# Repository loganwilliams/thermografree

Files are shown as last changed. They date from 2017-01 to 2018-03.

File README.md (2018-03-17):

# Thermografree

Thermografree is the first open source, medium resolution, and broadband forward looking infrared (FLIR) camera. It can be used as a thermographic camera, or for scientific imaging applications in the 2-18 um range.

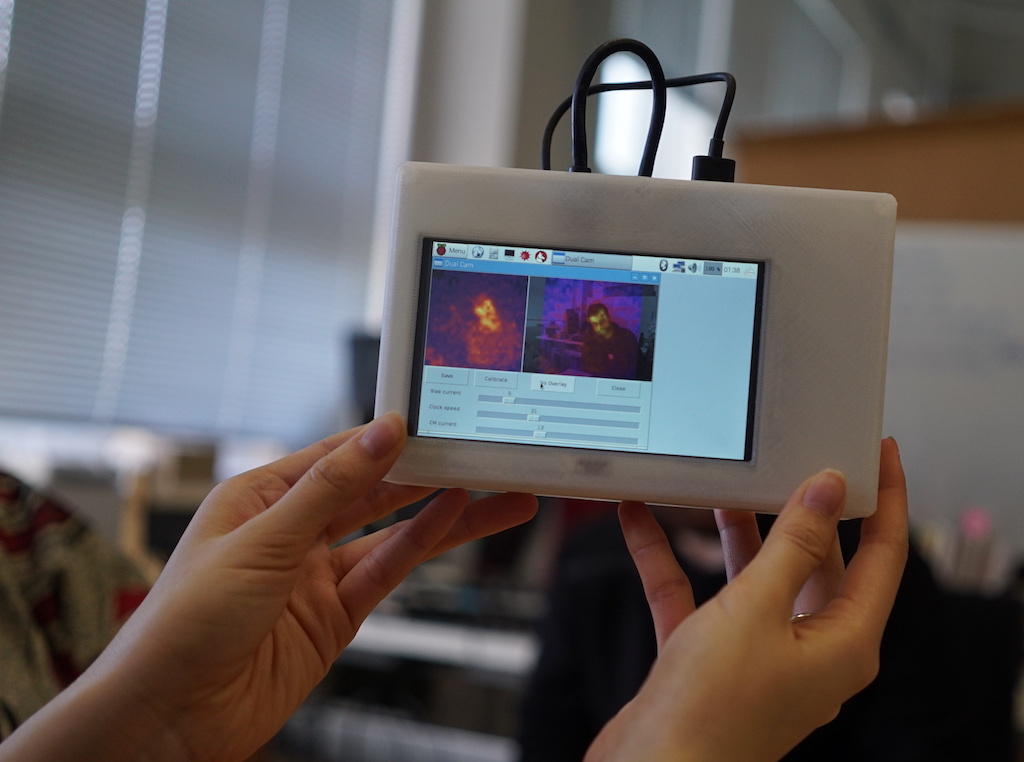
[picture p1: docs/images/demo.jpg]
The Thermografree device


This thermal camera is based on a Heimann Sensor thermopile array module, detailed in `docs/HeimannArrays9-9-16.pdf` and the sample datasheet (`docs/HTPA 32x32d L2.1_0.8 (Hi)S Rev2 Datasheet.pdf`). Previous attempts at open source thermal cameras have been based on the Melexis MLX90621, an earlier and lower resolution thermopile array. For comparison, the datasheet for this part is also available at `docs/MLX90621-Datasheet-Melexis.pdf`.

Code is in ```src/```, and should work out of the box on a Raspberry Pi with I2C enabled. If you are using an older (2015-2017) verison of the device, you will have to change the HTPA initialization to add an explicit `revision="2017"` in `dualcam.py`. Installation instructions are below.

OpenSCAD models for 3D printing are in ```case/```. The case and hardware (including the screen, cabling, and battery) are very minimum viable prototype, and should not in anyway be taken as "best practices" hardware advice.

Research on noise characteristics of the camera and possible uses/limitations for gas sensing are archived in ```docs/noise-analysis/```.

## Hardware

The hardware involved is extremely straightforward: a Raspberry Pi communicates with the Heimann sensor over I2C and displays the images to the user. The sensor should be connected to the Raspberry Pi GPIO pins 3 and 5, and can be powered from the 3.3V and ground pins of the GPIO port. This does not interfere with the use of SPI for touch screen communication. The system is powered from a USB power bank.

### Bill of materials

* Raspberry Pi Zero (or Raspberry Pi)
* LCD screen ([e.g.](https://www.amazon.com/SunFounder-Monitor-Display-800X480-Raspberry/dp/B01HXSFIH6)) and HDMI cable
* Raspberry Pi camera ([e.g.](https://www.amazon.com/dp/B01LY05LOE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))
* Heimann HTPA32x32dL3.6/0.9 (purchased through [Boston Electronics](http://www.boselec.com/))
* USB power bank ([e.g.](https://www.amazon.com/Anker-bar-Sized-Portable-High-Speed-Technology/dp/B00P7N0320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)) and USB cable with switch
* Case (3D printed files included in repository)
* Bracket for attaching Heimann sensor to case

## Software

The application consists of a Python class for interfacing with the module (```htpa.py```) and a GUI (```dualcam.py```). The GUI allows for control of the sensor clock frequency, current, and bias. The default settings are the settings used for the module factory calibration, and seem to produce the best results.

### Installation

#### Installing pre-requisites

The Python software has several pre-requisites. To install them on your Raspberry Pi, run the following commands while you have an internet connection.

```
sudo apt-get install python-pip ipython
sudo apt-get install python-numpy python-scipy
sudo apt-get install libopencv-dev python-opencv
sudo pip install periphery picamera imutils pillow
```

#### Enable I2C

Follow [Adafruit's tutorial](https://learn.adafruit.com/adafruits-raspberry-pi-lesson-4-gpio-setup/configuring-i2c).

#### Enabling I2C repeated starts

The I2C hardware on the Raspberry Pi needs to be configured to support "repeated starts." To do this, add the following line to ```/etc/modprobe.d/i2c.conf```:

```
options i2c-bcm2708 combined=1
```

If you are not using a Raspberry Pi, enabling repeated starts will likely require a different configuration. For more information, see [the blog post I wrote on this topic](http://exclav.es/2016/10/26/talkin-ir/).

## Known issues

* The sensor calibration programmed into the EEPROM at the factory does not seem to match the noise profile of the images captured from the device.
* The HDMI cable connection to a Raspberry Pi Zero is a hack. If you use the screen documented here, we suggest a Raspberry Pi 3.

## Physical assembly

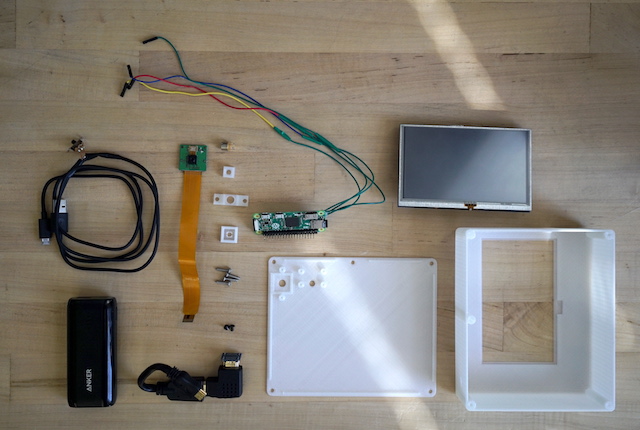
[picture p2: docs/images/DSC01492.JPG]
All parts


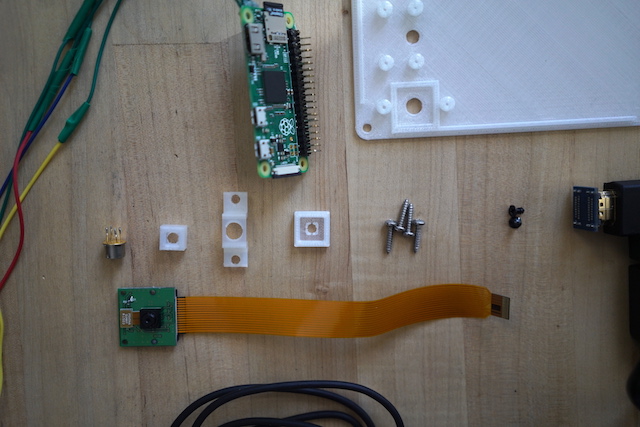
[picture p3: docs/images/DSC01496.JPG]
IR sensor assembly


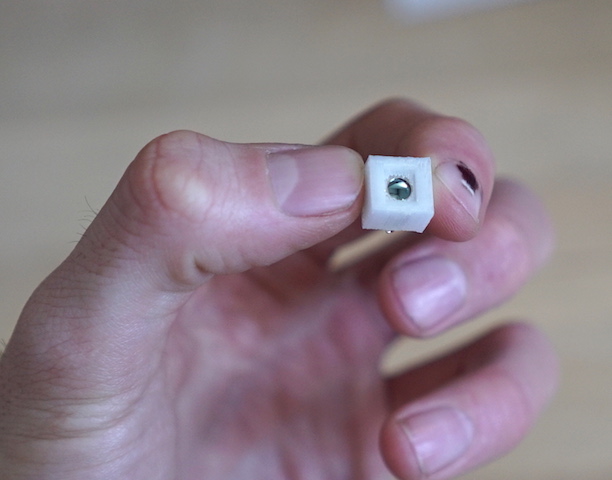
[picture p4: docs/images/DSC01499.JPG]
IR sensor in filter holder


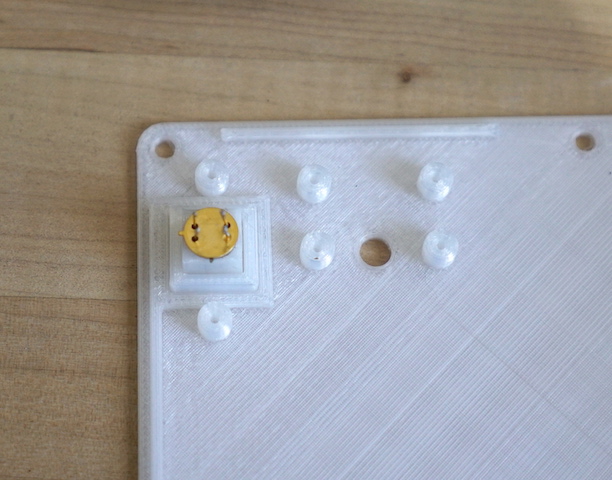
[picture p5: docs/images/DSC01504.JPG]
IR sensor placed in case


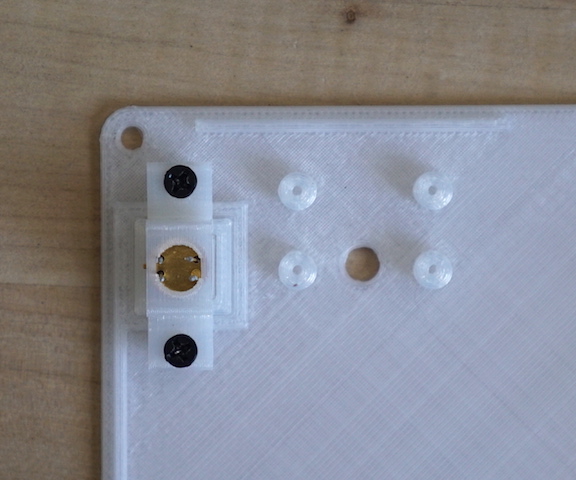
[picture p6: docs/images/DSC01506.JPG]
With bracket mounted


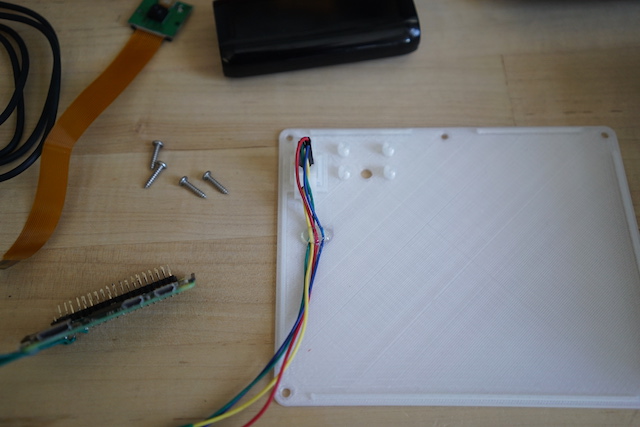
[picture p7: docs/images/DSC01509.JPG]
Stress relief


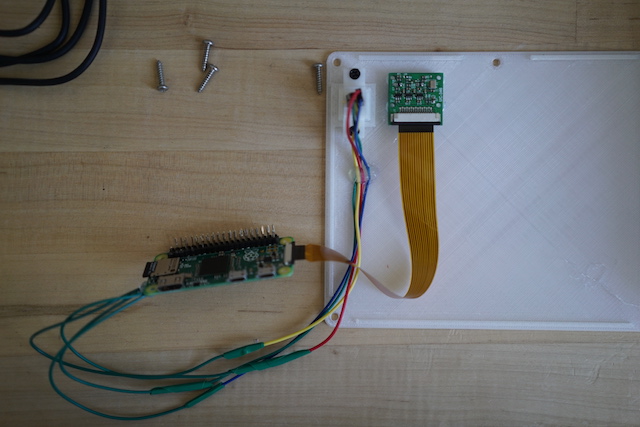
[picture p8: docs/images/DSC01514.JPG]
Visible camera mounted


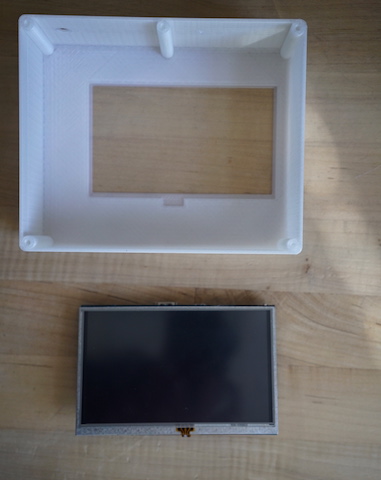
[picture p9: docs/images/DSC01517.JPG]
Screen and front case


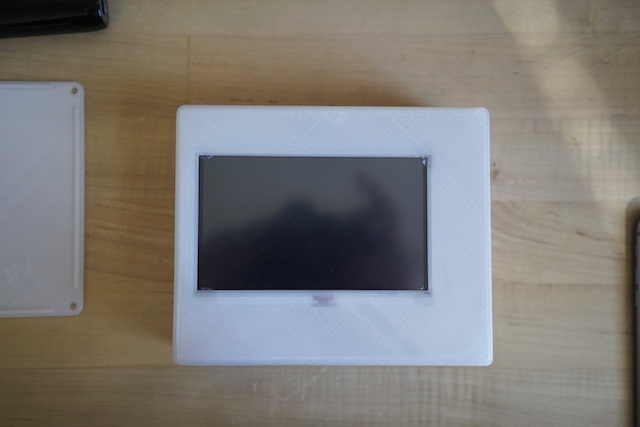
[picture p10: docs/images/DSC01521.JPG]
Screen mounted in front case


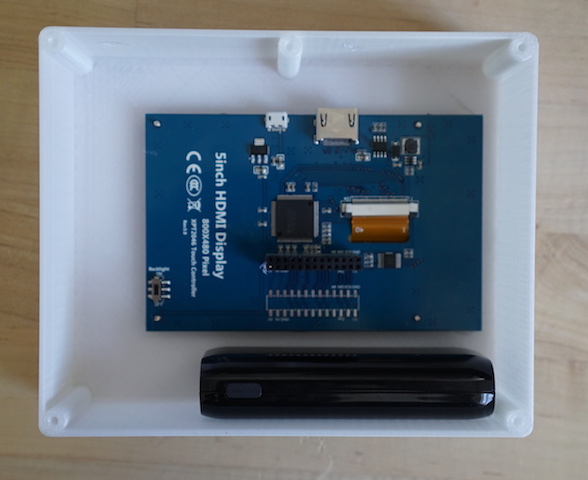
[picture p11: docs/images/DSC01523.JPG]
Battery mounted underneath screen


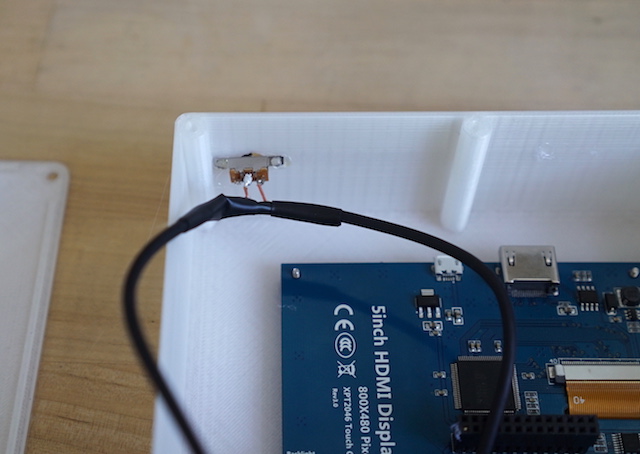
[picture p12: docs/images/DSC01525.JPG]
Switch glued to top of case


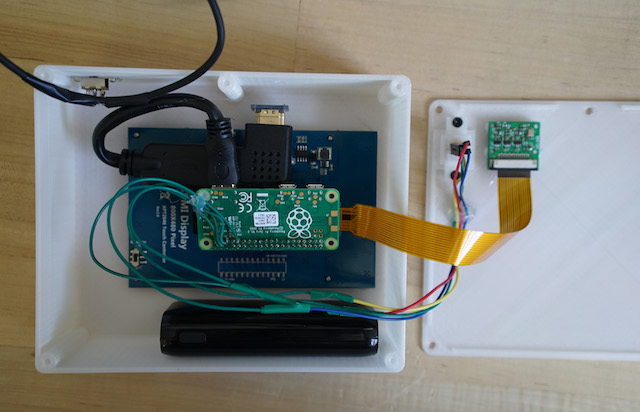
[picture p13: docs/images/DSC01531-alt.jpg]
HDMI cable connected


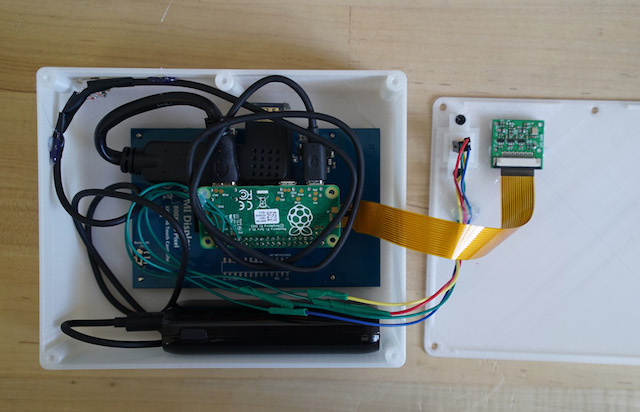
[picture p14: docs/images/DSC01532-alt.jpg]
HDMI and USB cable connected


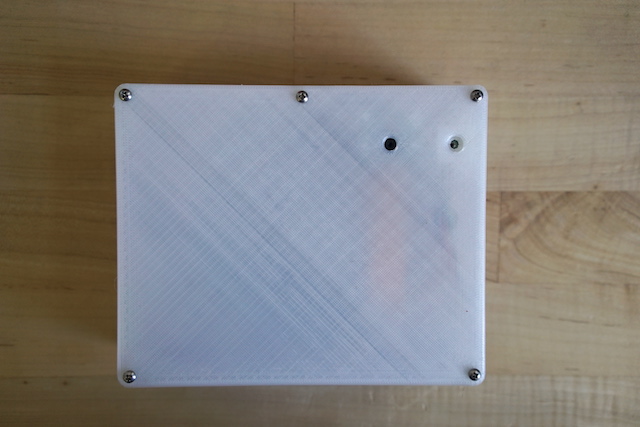
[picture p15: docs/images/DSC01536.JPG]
Back of case secured


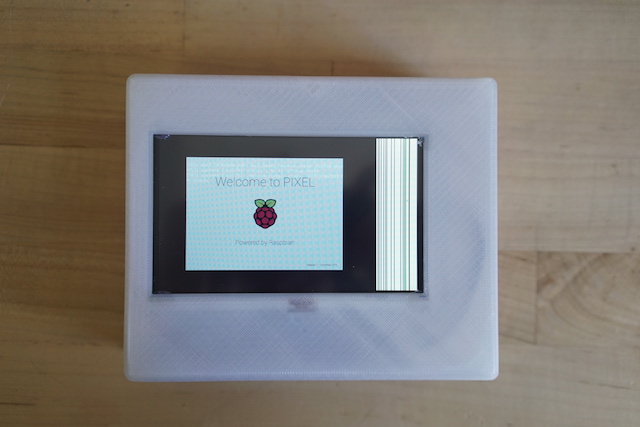
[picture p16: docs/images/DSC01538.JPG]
Booting up (with proper display settings, the whole screen is used.)


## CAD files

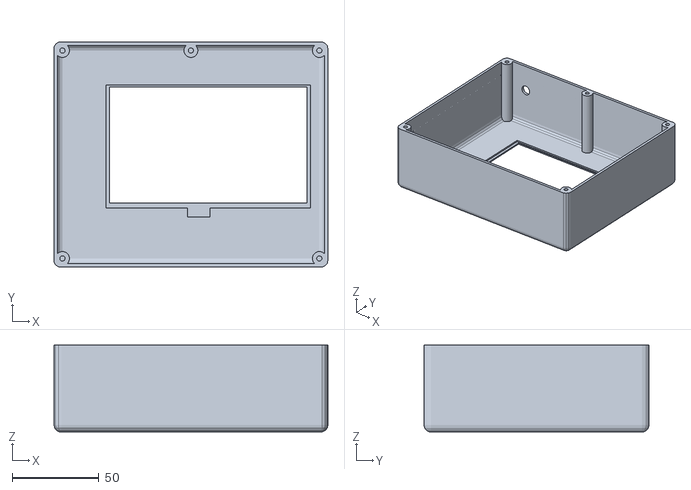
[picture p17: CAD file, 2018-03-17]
case/front.stl
158.0 x 129.8 x 49.9

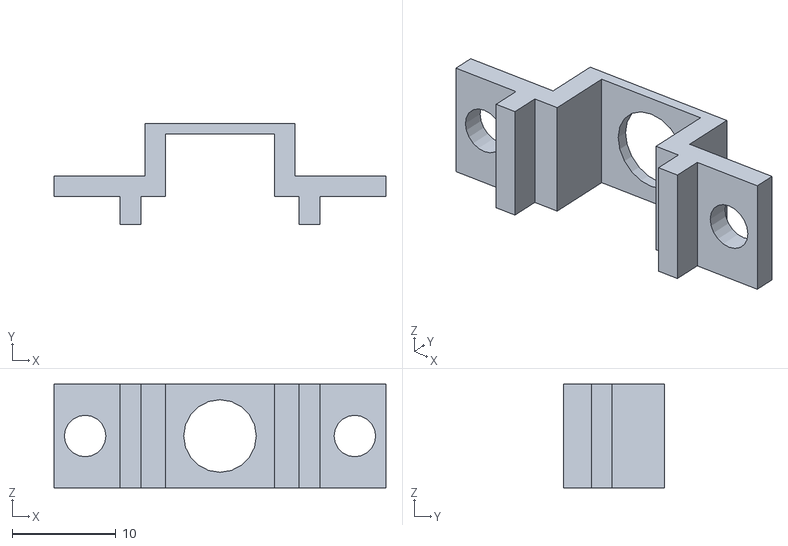
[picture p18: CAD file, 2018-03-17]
case/bracket.stl
32.0 x 9.75 x 10.0

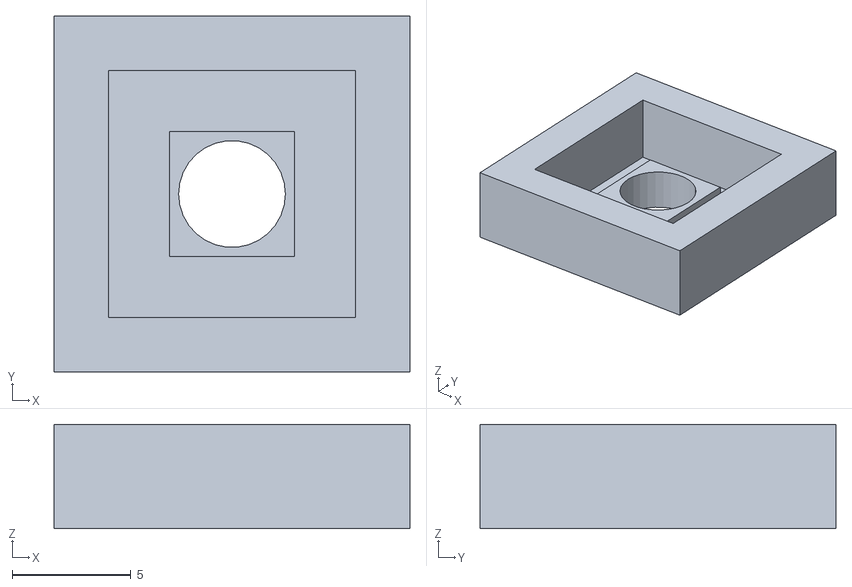
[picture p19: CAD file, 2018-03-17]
case/ir_sensor_cover_outer.stl
15.0 x 15.0 x 4.40

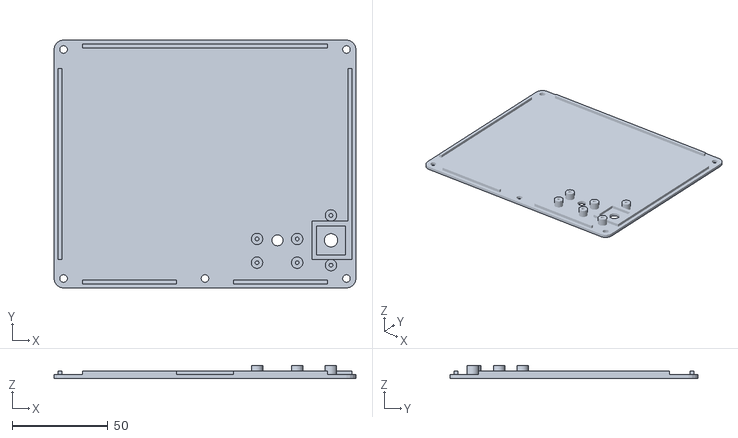
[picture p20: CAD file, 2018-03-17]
case/back.stl
158.1 x 129.9 x 6.70

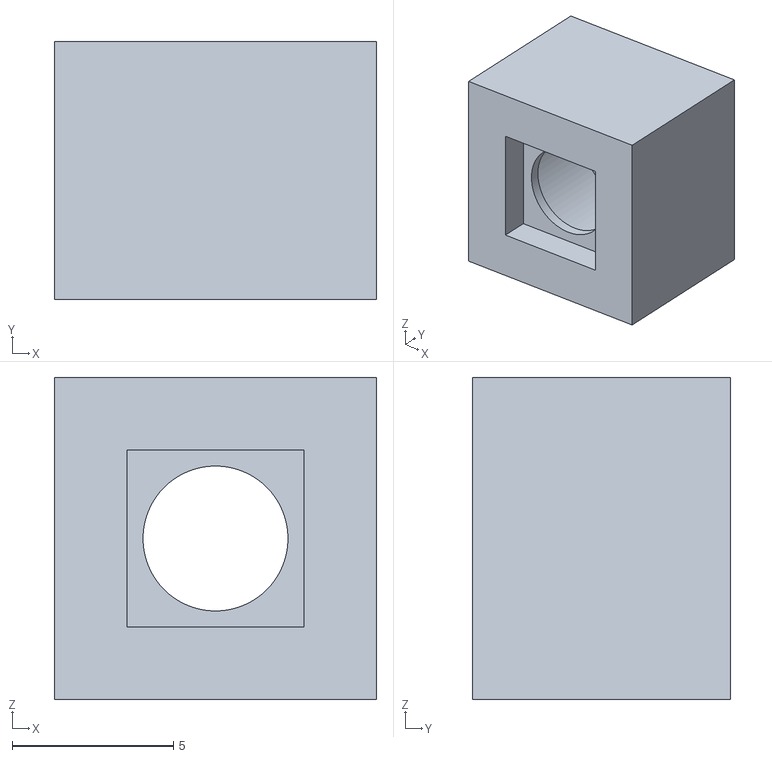
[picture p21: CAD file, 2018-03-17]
case/ir_sensor_cover.stl
10.0 x 8.00 x 10.0

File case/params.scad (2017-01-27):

module roundedRect(size, radius)
    {
    x = size[0];
    y = size[1];
    z = size[2];

    linear_extrude(height=z)
    hull()
    {
        // place 4 circles in the corners, with the given radius
        translate([radius, radius, 0])
        circle(r=radius);

        translate([x - radius, radius, 0])
        circle(r=radius);

        translate([radius, y - radius, 0])
        circle(r=radius);

        translate([x - radius, y - radius, 0])
        circle(r=radius);
    }
}

module roundedPoly(size, radius)
{
	x = size[0];
	y = size[1];
	z = size[2];

	hull()
	{
		// place 4 circles in the bottom corners, with the given radius
		translate([radius, radius, radius])
		sphere(r=radius);
	
		translate([x - radius, radius, radius])
		sphere(r=radius);
	
		translate([radius, y - radius, radius])
		sphere(r=radius);
	
		translate([x - radius, y - radius, radius])
		sphere(r=radius);
        
        // place 4 circles in the top corners, with the given radius
		translate([radius, radius, z - radius])
		sphere(r=radius);
	
		translate([x - radius, radius, z - radius])
		sphere(r=radius);
	
		translate([radius, y - radius, z - radius])
		sphere(r=radius);
	
		translate([x - radius, y - radius, z - radius])
		sphere(r=radius);
	}
}

module standoff(radius, height, inner_radius, depth=10) {
    difference() {
        cylinder(h=height, r=radius, $fn=40);
        translate([0, 0, height-20]) {
            cylinder(h=20.1, r=inner_radius, $fn=40);
        }
    }
}
    

left_margin = 10;
right_margin = 30;
top_margin = 25;
bottom_margin = 34;
screen_width = 118.1;
screen_height = 70.9;
height = 2;

total_width = left_margin+right_margin+screen_width;
total_height = top_margin+bottom_margin+screen_height;

ribbon_cable_width=13;

wall_thickness = 2;
depth = 50;
standoff_od = 4;

camera_offset_x = 105;
camera_offset_y = 12;
camera_standoff_height = 4.7;

sensor_offset_x = 135;
sensor_offset_y = 15;

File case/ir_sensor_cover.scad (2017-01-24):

module sensor_filter_bracket(module_height = 5,
                             total_height = 8,
                             outer_radius = 5,
                             inner_radius = 2,
                             filter_height = 0.1,
                             filter_width = 5,
                             viewport_width = 3.5) {

    difference() {
        // This is the main cylinder
        //cylinder(h=total_height, r=outer_radius, center=false, $fn=100);
        translate([-outer_radius, -outer_radius, 0]) {
            cube([outer_radius*2, outer_radius*2, total_height]);
        }
        
        // Remove a cutout for the sensor module
        translate([0, 0, -0.01]) {
            cylinder(h=module_height + 0.01, r=inner_radius, center=false, $fn=100);
        };
        
        translate([0, 0, module_height-0.01]) {
            cylinder(h=total_height - module_height + 0.02, r=viewport_width, center=false, $fn=100);
        }
        
        // Remove a cut out for the filter
        //translate([-filter_width/2, (-viewport_width-0.1), module_height+0.1]) {
        //    cube([filter_width, outer_radius*2, filter_height]);
        //};
        
        // Remove a wider cutout from the top for imaging
        //translate([0, 0, module_height - 0.01]) {
        //    cylinder(h=(total_height - module_height + 0.02), r=viewport_width, center=false, $fn=100);
            //cylinder(h=(total_height - module_height - 0.48), r1=(2), r2=(outer_radius - 1), center=false, $fn=100);
        //};
        
        translate([-(filter_width+0.5)/2, -(filter_width+0.5)/2, module_height + 0.5]) {
            cube([filter_width+0.5, filter_width+0.5, total_height-module_height+0.05]);
        }
        
        // Remove a wider cutout from the side for filter insertion and removal
        //translate([-outer_radius, (inner_radius+0.25), (module_height-1)]) {
        //    cube([outer_radius*2, outer_radius, (total_height - module_height + 1.1)]);
        //}
    }   
}

rotate([90, 0, 0]) {

sensor_filter_bracket(module_height = 6.1,
                                            total_height = 8,
                                            outer_radius = 5,
                                            inner_radius = 8.65/2,
                                            filter_height = 0.65,
                                            filter_width = 5,
                                            viewport_width = 2.25);
}

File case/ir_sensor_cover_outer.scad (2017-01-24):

height = 1.9;
thickness = 0.5;

difference() {
    translate([-15/2, -15/2, 0]) {
        cube([15, 15, height+2.5]);
    }
    
    difference() {
        translate([-5.2, -5.2, thickness]) {
            cube([10.4, 10.4, height+2.5]);
        }
        
        translate([-5.25/2, -5.25/2, thickness]) {
            cube([5.25, 5.25, height]);
        }
    }
    
    translate([0, 0, -0.1]) {
        cylinder(r=2.25, h=10, $fn=30);
    }
}

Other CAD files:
case/back.scad
case/bracket.scad
case/camera_bracket.scad
case/front.scad
case/test.scad

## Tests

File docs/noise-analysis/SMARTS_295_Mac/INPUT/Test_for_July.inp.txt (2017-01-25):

'USSA_AOD=0.084_ASTM_G173'
1
1013.25 0 0
1
'USSA'
1
1
1
370
0
'S&F_RURAL'
0
0.084
38
1
38 37. 180.
280 4000 1.0 1366.1
2
280 4000 .5
3
8 9 10
1
0 2.9 0
0
0
0
2
1.5

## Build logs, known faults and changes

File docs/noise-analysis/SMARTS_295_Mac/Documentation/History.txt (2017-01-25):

SMARTS--Simple Model of the Atmospheric Radiative Transfer of Sunshine

                        Developed by C. Gueymard

                                  *****

   THE CHANGES THAT OCCURRED IN THE SUCCESSIVE VERSIONS OF SMARTS2 ARE
   DOCUMENTED BELOW.
 
*	Version 2.0, Feb. 1994, corresponds to the ASES SOLAR'94 Conf. paper: 
	"Updated transmittance functions for use
	in fast spectral direct beam irradiance models"

*	Version 2.5, June 1994. Revisions include:
	- Modified extraterrestrial spectrum with new data from UARS
		(pers. comm. with Michael van Hoosier, NRL, May 1994)
	- Revised water vapor and mixed gases absorption coefficients
	- Revised water vapor and mixed gases transmittance functions
	- Revised diffuse irradiance on the horizontal
	- Revised transposition for tilted planes (returning to isotropic
		for wavelengths < 0.35 µm)
	- Added new default values when using reference atmospheres at
		elevated sites (up to 4 km altitude) with interpolation
		using a 4 pt. Lagrange scheme
	- Improved input data handling
	- Use a fit of alpha = f(humidity) for each default aerosol type
	- Use a fit of omegl=f(humidity, wavelength) for each aerosol type

*	Version 2.5.1, July 1994 with the following revisions:
	- Fixed error resulting from input card 4a for IH2O=2
	- Modified the calculation of relative humidity so that RH=0.0 if 
	the user inputs W=0.
	- Modified the relationship between turbidity and visibility (input
	card 9a with ITURB=3 or 4) by replacing the King & Buckius equation
	by a newly-developed fit based on Shettle & Fenn/MODTRAN2 results.
	- Added the calculation of the extra-terrestrial illuminance and
	luminous efficacy.

*	VERSION 2.5.2, Aug. 1994
	- Fixed error when §=0. is input
	- Fixed initialization of E.T. illuminance
	- Corrected formula for luminous efficacy of the E.T. spectrum

*	VERSION 2.5.3, Aug. 1994
	- Fixed inconsistencies related to the choice of using
	reference atmospheres
	- Modified the input sequence accordingly; TAIR, RH and SEASON
	are now required whenever a ref. atm. is not selected. See new
	comments on CARDS 2, 3 and 4.
	- It is now possible to have the pressure determined or interpolated
	from the ref. atm. data file.
	- Used a simplified fit for THICK.
	- Added a correction for the temperature gradient to estimate
	TGRND (sea-level temperature) from TAIR when a user defined atm.
	is selected and Z>0.

*	VERSION 2.6, Oct. 1994
	- Modified the calculation of the sun's position, now using the 
	Astronomical Almanac "low precision formula", with which declination
	is accurate to better than 0.01 deg. Refraction is considered
	prior to calculation of optical masses and
	now depends on pressure and temperature. 
	Note that Z (APPARENT zenith angle) must be ²91 deg. 
	Z>90 deg. means that the sun is below the apparent horizon; it may still
	be visible at sunrise/sunset in mountain areas or from an airplane.
	However, the accuracy for Z>85 deg. is questionable in most parts of
	the spectrum due to lack of reference data. (The accuracy is
	good, at least in the UV-B, for Z<89.5 deg.) 
	Time must now be entered as LST (Local Standard Time), therefore, no
	adjustment is needed for Daylight Savings Time.
	Day must now be entered as the day-of-year number (e.g., 32 for Feb. 1)
	Note that input card 17a has been modified accordingly.
	Changed the sign convention for azimuths and longitudes (to conform to
	the astronomical convention).
	- Corrected the default O3 values for the 4 supplementary atmospheres.
	- Added default values for the NO2 total column, corresponding to
	stratospheric loading only; a new input card is added, asking
	if the default OR the user value of NO2 shall be used.
	- Added 3 standard aerosol types from the SRA/IAMAP atmospheric model;
	the input aerosol types names have been changed for clarity.
	- Corrected the function beta=f(Visi) to obtain beta=0 if Visi=340 km
	(its maximum value for a pure Rayleigh atmosphere).
	- Corrected the fits to obtain OMEGL (the aerosol single scattering
	albedo) more accurately for the SRA and Shettle & Fenn aerosol models.
	- Introduced a new function to calculate FA (the aerosol forward
	scatterance) as a function of zenith angle and asymmetry parameter.
	- Introduced fits to obtain the asymmetry parameter, g, as a function
	of wavelength and humidity, for the reference aerosol types; 
	if the aerosol is user-defined, g becomes a necessary input, but
	is considered constant throughout the spectrum.
	- Modified the circumsolar correction factor to have a variable
	opening angle of the simulated radiometer; a new input card is added
	to ask if the circumsolar correction shall be calculated; if yes, the
	radiometer total opening angle input is asked for.
	- Modified the input of air temperature, so that the average O3 temp.
	is now calculated from a daily average instead of the previously used 
	instantaneous value.
	- Modified the sky reflectance function in the UV so that it is now
	close to rigorous predictions.
	- Modified the diffuse radiation parameterization to match reference
	caculations and measurements in the UV, down to about 280 nm.
	- Added DOUBLE PRECISION for some variables that decrease to near
	zero in the UV.
	- Added optional calculations in the UV (see new input card 16),
	with UV-A and UV-B total irradiances, as well as band irradiances 
	weighted by some action spectra for erythema, ADN damage, etc.
	- Corrected a small bug in the filter/scanning function.
	
*	VERSION 2.6.1, Nov. 1994
	- Moved the comments on the input cards that were in the main program
	into the README.TOO file.
	- Fixed a bug in the ozone optical thickness calculation (that
	could become <0 at very low temperatures).
	- Improved the calculation of the aerosol forward scatterance and
	ozone pseudo-transmittance for a better diffuse irradiance
	determination (it was too low in the visible with v. 2.6).
	- Replaced the (probably incorrect) fit by Bjorn of the Parrish et al.
	action spectrum by fits for the recently published SCUP (Skin Cancer 
	Utrecht-Philadelphia) action spectra of de Gruijl & Van der Leun (1994).
	- Improved the formatting of some outputs.
	- Cleaned the SPCTRM.DAT file for extraneous data (tip courtesy of 
	Dr. Kambezidis).
	- Added more Double Precision variables to avoid possible computational
	problems with some Fortran compilers (tip courtesy Dr. Molineaux).
	
*	VERSION 2.6.2, Dec. 1994, corresponds to FSEC report PF-270-94
	- Added XCHECK as a Double Precision variable.
	- Removed all X-marks in the first column as they may not be
	interpretable by some compilers.
	- Corrected some misprinted ozone absorption coefficients
	for the UV-A band in SPCTRM.DAT.
	- Corrected some misprinted mixed gas absorption coefficients
	above 2000 nm in SPCTRM.DAT.
	
*	VERSION 2.6.3, Jan. 1995
	- Fixed minor inconsistencies in the way ground and sea-level
	temperatures were echoed.
	- Fixed minor inconsistencies in the way wavelengths and wavelength
	intervals were used during the numerical integration process leading to
	broadband results. Full spectrum (280-4000 nm) integrations remain
	unchanged, but partial integrations may slightly differ.
	- Changed Real to Integer formats for the wavelength inputs and in most
	calculations.
	- Introduced the option ILLUM=2 to specifically calculate the luminous
	efficacy (ILLUM=1 does not offer this time consuming result any more).
	- Added an executable for PC users, as compiled by MS Fortran 5.1.
	- Corrected a missing digit in the last coefficient of the VLAMBDA.DAT
	file.
	
*	VERSION 2.7, Oct. 1995
	- Replaced the interim broadband circumsolar correction by a physical
	model. This calculation is optional and use the aerosol model selected by
	the user. A maximum 10¡ half cone is considered, with single scattering
	from aerosols and multiple scattering by molecules. The actual penumbra
	function of the simulated radiometer can be approximated from its geometry.
	- Replaced the fixed broadband albedos (zonal and local) by user-selected
	albedo models. Besides the fixed broadband Lambertian albedo option, a 
	user-defined spectral reflectance dataset can be read (from file 
	ALBEDO.DAT) and be specified either Lambertian or non-Lambertian. The non-
	Lambertian option will add calculations for increased reflectance at
	larger zenith angles. The calculation of spectral, non-Lambertian 
	reflectance of water (or calm oceans) is also optional. A library of 16
	user-selectable spectral reflectance datasets is offered for different
	natural and artificial surfaces. They are considered non-Lambertian.
	The zonal and local reflectances thus defined can be the same or not.
	- The calculation of irradiances on a tilted plane is now optional. A
	tracking surface (always normal to the sun rays) can be defined.
	- Modified the diffuse irradiance transposition for tilted surfaces. The
	transition between the isotropic and anisotropic calculations now depends
	on the ratio between the aerosol and Rayleigh optical thicknesses.
	- The spectral results can be output to either one or both of the regular
	output file (SMARTS2.OUT) and the spreadsheet file (SMARTS2.EXT). The
	latter's content is optional, for a maximum of 24 variables to be selected
	from a maximum of 32 possible. Each column has a header. This file can be
	read directly by a spreadsheet or graphics program.
	- Modified the optical air mass iterative algorithm. Its acceptable
	maximum value is now 57.3 (for a zenith angle of 91.0¡).
	- Fixed minor inconsistencies in the solar position algorithm.
	- Fixed minor errors in the extraterrestrial spectrum.
	- Fixed a bug in the scanning function.
	- Used different compilers: Language Systems Fortran 3.3 for the Mac
	version, and Lahey Fortran 5.01 for the PC/DOS version. The Mac version
	has three different executables optimized for different machines.
	- Fixed a bug affecting pressure corrections with ISPR=0. (Fixed 
	18 Mar. 96).
	- Fixed a bug affecting the PC version only, which could not produce a
	correct backscattering calculation over a Lambertian surface. (Fixed
	1 Aug. 96).
	
*	VERSION 2.8, Nov. 1996
	- Fixed a bug in the temperature correction of ozone absorption. It
	affected wavelengths in the 561-1091 and 3120-3750 nm spectral ranges.
	(Thanks to Benoit Molineaux.)
	- Modified the extraterrestrial spectrum in the 412-4000 nm range to
	reflect the new spectrum in MODTRAN3. It is essentially a degraded version
	of the latter's relatively high-resolution spectrum (1 cm-1 intervals),
	with some corrections. The essential difference is around the 940-nm water
	vapor band, where the irradiance is now 2-4% larger. The 280-4000 nm
	irradiance is now 1349.7 W/m2, compared to 1349.5 previously, and
	1354.1 W/m2 for MODTRAN3.
	- Introduced another option in illuminance calculations. The ILLUM
	parameter may now be set to -2, -1, 0, 1 , or 2. 
	ILLUM=0 is for no illuminance calculations, as before.
	ILLUM=-1 or 1 is for supplemental illuminance calculations. 
	ILLUM=-2 or 2 is for both supplemental illuminance and luminous efficacy
	calculations. 
	ILLUM=-1 and -2 have been introduced so that the old CIE (1924) Vlambda 
	curve (for the standard eye response) in file VLAMBDA.DAT could still be
	used. (Note, however, that this file has been slightly changed to allow
	extended calculations to 780 nm.)
	ILLUM=1 and 2 now use the newer CIE (1988) Vlambda curve, with added
	accurracy, significant digits, and values up to 780 nm. The new dataset is
	in file VMLAMDA.DAT. (Thanks to Dominique Dumortier.)
	- Added a user-friendly interface to change the input and output filenames
	when the execution begins. (Thanks again to Dominique Dumortier.)
	- Changed the compiler for the Mac version. A single, fat binary
	executable for Mac is now offered, which will run native on both 68K and
	PPC machines. It is also accelerated for the PowerPC 604 chip.

*	VERSION 2.9.x, Feb. 2002 and later
	All new features are documented in the file 'SMARTSxxx_Users_Manual.pdf'.

	PLEASE REPORT ANY PROBLEM TO THE AUTHOR!
	
	Dr. Chris Gueymard
	Solar Consulting Services
 	P.O. Box 392
 	Colebrook, NH 03576
 	USA
 	Tel. (603) 237-8550
	Fax  (603) 237-5314
 	Email: Chris@solarconsultingservices.com

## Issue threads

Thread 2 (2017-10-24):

Issue with Reading sensor

stilmon, 2017-10-24:
i see the sensor conencted

     0  1  2  3  4  5  6  7  8  9  a  b  c  d  e  f
00:          -- -- -- -- -- -- -- -- -- -- -- -- --
10: -- -- -- -- -- -- -- -- -- -- 1a -- -- -- -- --
20: -- -- -- -- -- -- -- -- -- -- -- -- -- -- -- --
30: -- -- -- -- -- -- -- -- -- -- -- -- -- -- -- --
40: -- -- -- -- -- -- -- -- -- -- -- -- -- -- -- --
50: 50 -- -- -- -- -- -- -- -- -- -- -- -- -- -- --
60: -- -- -- -- -- -- -- -- -- -- -- -- -- -- -- --
70: -- -- -- -- -- -- -- --

when i start the application i get

root@Wello9944:~/wello# python2 ./dualcam.py
Initializing capture settings
Grabbing EEPROM data
applying command
('cm', 12)
applying command
('clock', 21)
applying command
('bias', 5)
Capturing image

which tells me it finds the sensors..  but all iget on the left screen is a black screen, i cannot calibrate or see any visual. suggestions?  htpa.pyc gets output in the folder as well

mfassler, 2018-02-28:
Hi stilmon,

Have you tried my fork?
https://github.com/mfassler/thermografree/tree/develop

loganwilliams, 2018-02-28:
@stilmon, I apologize for the delay in addressing this. Could you send me the datasheet for your sensor and the version info for your Raspberry Pi? If @mfassler's fork works for you, that would also be helpful information.

stilmon, 2018-02-28:
Hi Logan

Sensor is HTPA.32X32d

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

loganwilliams, 2018-03-10:
Does @mfassler's fork work for you?

loganwilliams, 2018-03-11:
It is linked above: https://github.com/mfassler/thermografree/tree/develop

stilmon, 2018-03-12:
Yes this was done for old version of sensor; it is not correct for the sensor we are using,

Sent via the Samsung Galaxy S7 edge, an AT&T 4G LTE smartphone

-------- Original message --------
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

loganwilliams, 2018-03-12:
I'm going to need more information to be able to help. Could you provide:
* The revision number of the *sensor* and of the *datasheet* you have? Preferably a scan or a photo of the datasheet.
* The hardware you are using: A Raspberry Pi? Something else? What version of the Raspberry Pi? What OS is it running?
* Anything that you've done to configure SPI. (Have you enabled repeated-starts? If you haven't, try that: http://exclav.es/2016/10/26/talkin-ir/)

Let me know when you have tried these things/can provide that information.

stilmon, 2018-03-12:
Copying our main dev. Tim see below

Sent via the Samsung Galaxy S7 edge, an AT&T 4G LTE smartphone

-------- Original message --------
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

stilmon, 2018-03-12:
This code will not work with the current version of sensor we are using 1.3
specifically line 49 is wrong, it changed v1.2 to v1.3  I am using the
table lookup with the VDD adjustments for v1.3 (much more complicated) my
doc is rev 21 2017.11.02 I’ve attached the sample calculation.

On Sun, Mar 11, 2018 at 9:18 PM Scott Cadieux <scott.cadieux@welloinc.com>
wrote:

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
--

- - - - - - - - - - - - - - - - -
Tim Regan
Tcubed - Owner
Phone: (602) 992-2570

stilmon, 2018-03-13:
I've put together a excel spreadsheet to analyze the data and formula's I'm
using with the v1.3 sensor. (with variable names that match the
documentation).
My test app (optionally) writes these values to a .csv file for diagnostics.
I'm also having problems with the amount of noise from the sensor, for a
brief period a solid, same temp surface was +/- 8 degrees, but now I'm
seeing more like a range of 22-24F,
My solution was to average the last 5 frames of data, to smooth it out,
however I still have some pixels that seem to stay high and others seem
low, and my avg temp is below what I would expect.  I've attached the
latest version of the documentation (that I have).

I've been working with Heimann in Germany to try to resolve these
issues....It's been slow going
I'm going to start work on the 90 degree field of view sensor (different
tables) as soon as it arrives.

Below is the python version of the table look up code that is referred to
on page 20 & 21 of the documentation

    #/********************************************************************
    # * Function:        void calcTO(unsigned int TAmb, signed int dig,
unsigned long PiC)
    # *
    # * Description:     calculate the object temperature via look-up table
    # *
    # * Dependencies:    ambient temperature (TAmb), pixel voltage
(dig),  pixel
sensitivity coefficients (PiC)
    # *******************************************************************/
def calcTO(self, TAmb, dig, PiC, dontCalcTA):
Tobject = 0
y = 0
val = 0
vx = 0
vy = 0
ydist = 0
CurTACol = 0
dTA = 0
scale = 0

#//first check the position in x-axis of table
if (dontCalcTA == False):
                  #ALWAYS FALSE
for CurTACol in range(defs.NROFTAELEMENTS-1):
if ((Table.XTATemps[CurTACol] <= TAmb) and (Table.XTATemps[CurTACol+1] >
TAmb)):
break
dTA = TAmb - Table.XTATemps[CurTACol]
#print('dTA: ' + str(dTA))
if (CurTACol >= (defs.NROFTAELEMENTS-1)):
return 0

#//now scale dig to PCSCALEVAL
scale = defs.PCSCALEVAL * dig
#print('scale: ' + str(scale))
vx = scale / PiC
#print('vx: ' + str(vx))

val = vx + defs.TABLEOFFSET
#//now determine row
y = int(val) >> defs.ADEXPBITS
ydist = defs.ADEQUIDISTANCE
if (y < (defs.NROFADELEMENTS-1)):
if (Table.TempTable[y][CurTACol]):
vx = (((Table.TempTable[y][CurTACol+1] - Table.TempTable[y][CurTACol]) *
dTA) \
/ defs.TAEQUIDISTANCE) + Table.TempTable[y][CurTACol]
vy = (((Table.TempTable[y+1][CurTACol+1] - Table.TempTable[y+1][CurTACol])
* dTA) \
/ defs.TAEQUIDISTANCE) + Table.TempTable[y+1][CurTACol]
Tobject = (vy-vx) * (val - Table.YADValues[y]) / ydist + vx
else:
return 0
else:
return 0

Tobject += self.GlobalOffset
return np.round(Tobject,2)

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

--

- - - - - - - - - - - - - - - - -
Tim Regan
Tcubed - Owner
Phone: (602) 992-2570

loganwilliams, 2018-03-17:
The noise issues sound like a hardware problem, that I am unable to address.

I did not write the code that Heimann provided, and I can't troubleshoot it or provide support for you. If you upload a copy of your datasheet and provide the information that I asked for last week, I would be interested in modifying my project to support other revisions of the sensor. But without that information, I will have to close this issue.

If you provide more information, please log in to the Github website and comment on this issue directly rather than emailing. That is the only way to add an attachment -- I will not receive emailed attachments. It also helps with the formatting.

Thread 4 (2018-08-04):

Blocked after Exposing block 1

AmalMak, 2018-08-04:
Hi, thanks for this terrific project. I'm currently having an issue when I run the ''capture_display.py'' code on my raspberry pi zero.

After exposing the data from block 0, the code enters an infinite loop at block 1 because of the received data from the query (which is 1) is not similar to the expected one (which is 5)!

Could you please help me out in identifying what could the problem here? Thanks!

Closed 2018-08-08.

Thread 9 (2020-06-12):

htpa.py not working

Grandpa-G, 2020-06-12:
in the htpa.py script around line 171, the loop is never broken. The value of query[1].data[0] is 1 for the first block and so the loop keeps looping.

I am using the Heimann 32x32 sensor and it works with their software ok. Is there something I am doing wrong?

skpick99, 2020-06-13:
Change line 167 from:         expected = 1 + (block << 2)
to:                                         expected = 1 + (block << 4)

If that doesn't work, uncomment the print statement on line 176 and see report what was (1) received and (2) what was expected.

Grandpa-G, 2020-06-13:
I did that and it seems to run now. However, capture_display, I only get black/white and it looks like a  high level camera shot of mars surface, just splotches. Running dualcam is yellow to red but never changes. Is this what it should do?
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

Grandpa-G, 2020-06-13:
I think I got dualcam working, I just had to calibrate it.

Grandpa-G, 2020-06-13:
Is it possible (easy) to get temperatures from you code?

nicofrago, 2020-07-04:
Hello,
it is still not working for me, I got:
Not ready, received 142, expected 1
and for me block is always 0

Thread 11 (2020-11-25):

Details on What happening on this line below.

Raj9417, 2020-11-25:
def get_eeprom(self, eeprom_address=0x50):
		# Two separate I2C transfers in case the buffer size is small
		**q1 = [I2C.Message([0x00, 0x00]), I2C.Message([0x00]*4000, read=True)]
		q2 = [I2C.Message([0x0f, 0xa0]), I2C.Message([0x00]*4000, read=True)]**
		self.i2c.transfer(eeprom_address, q1)
		self.i2c.transfer(eeprom_address, q2)
		return np.array(q1[1].data + q2[1].data)

The function above was taken from htpa.py code. what I underastand is you are reading 4000 number of bytes from 4 location from the EEPROM, (0x00,0x00,0x0f,0x0a). Please explain this two line I bold up in the function on what is happening and is my understanding correct?

Thank You.

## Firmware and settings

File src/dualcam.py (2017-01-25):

from Tkinter import *
import cv2
import numpy as np
from PIL import ImageTk, Image
import Queue
import time
import threading
from picamera.array import PiRGBArray
from picamera import PiCamera
from imutils.video import VideoStream
import imutils
from htpa import *
import pickle
import copy

colormap = np.array([[[0,0,4],[1,0,5],[1,1,6],[1,1,8],[2,1,10],[2,2,12],[2,2,14],[3,2,16],[4,3,18],[4,3,20],[5,4,23],[6,4,25],[7,5,27],[8,5,29],[9,6,31],[10,7,34],[11,7,36],[12,8,38],[13,8,41],[14,9,43],[16,9,45],[17,10,48],[18,10,50],[20,11,52],[21,11,55],[22,11,57],[24,12,60],[25,12,62],[27,12,65],[28,12,67],[30,12,69],[31,12,72],[33,12,74],[35,12,76],[36,12,79],[38,12,81],[40,11,83],[41,11,85],[43,11,87],[45,11,89],[47,10,91],[49,10,92],[50,10,94],[52,10,95],[54,9,97],[56,9,98],[57,9,99],[59,9,100],[61,9,101],[62,9,102],[64,10,103],[66,10,104],[68,10,104],[69,10,105],[71,11,106],[73,11,106],[74,12,107],[76,12,107],[77,13,108],[79,13,108],[81,14,108],[82,14,109],[84,15,109],[85,15,109],[87,16,110],[89,16,110],[90,17,110],[92,18,110],[93,18,110],[95,19,110],[97,19,110],[98,20,110],[100,21,110],[101,21,110],[103,22,110],[105,22,110],[106,23,110],[108,24,110],[109,24,110],[111,25,110],[113,25,110],[114,26,110],[116,26,110],[117,27,110],[119,28,109],[120,28,109],[122,29,109],[124,29,109],[125,30,109],[127,30,108],[128,31,108],[130,32,108],[132,32,107],[133,33,107],[135,33,107],[136,34,106],[138,34,106],[140,35,105],[141,35,105],[143,36,105],[144,37,104],[146,37,104],[147,38,103],[149,38,103],[151,39,102],[152,39,102],[154,40,101],[155,41,100],[157,41,100],[159,42,99],[160,42,99],[162,43,98],[163,44,97],[165,44,96],[166,45,96],[168,46,95],[169,46,94],[171,47,94],[173,48,93],[174,48,92],[176,49,91],[177,50,90],[179,50,90],[180,51,89],[182,52,88],[183,53,87],[185,53,86],[186,54,85],[188,55,84],[189,56,83],[191,57,82],[192,58,81],[193,58,80],[195,59,79],[196,60,78],[198,61,77],[199,62,76],[200,63,75],[202,64,74],[203,65,73],[204,66,72],[206,67,71],[207,68,70],[208,69,69],[210,70,68],[211,71,67],[212,72,66],[213,74,65],[215,75,63],[216,76,62],[217,77,61],[218,78,60],[219,80,59],[221,81,58],[222,82,56],[223,83,55],[224,85,54],[225,86,53],[226,87,52],[227,89,51],[228,90,49],[229,92,48],[230,93,47],[231,94,46],[232,96,45],[233,97,43],[234,99,42],[235,100,41],[235,102,40],[236,103,38],[237,105,37],[238,106,36],[239,108,35],[239,110,33],[240,111,32],[241,113,31],[241,115,29],[242,116,28],[243,118,27],[243,120,25],[244,121,24],[245,123,23],[245,125,21],[246,126,20],[246,128,19],[247,130,18],[247,132,16],[248,133,15],[248,135,14],[248,137,12],[249,139,11],[249,140,10],[249,142,9],[250,144,8],[250,146,7],[250,148,7],[251,150,6],[251,151,6],[251,153,6],[251,155,6],[251,157,7],[252,159,7],[252,161,8],[252,163,9],[252,165,10],[252,166,12],[252,168,13],[252,170,15],[252,172,17],[252,174,18],[252,176,20],[252,178,22],[252,180,24],[251,182,26],[251,184,29],[251,186,31],[251,188,33],[251,190,35],[250,192,38],[250,194,40],[250,196,42],[250,198,45],[249,199,47],[249,201,50],[249,203,53],[248,205,55],[248,207,58],[247,209,61],[247,211,64],[246,213,67],[246,215,70],[245,217,73],[245,219,76],[244,221,79],[244,223,83],[244,225,86],[243,227,90],[243,229,93],[242,230,97],[242,232,101],[242,234,105],[241,236,109],[241,237,113],[241,239,117],[241,241,121],[242,242,125],[242,244,130],[243,245,134],[243,246,138],[244,248,142],[245,249,146],[246,250,150],[248,251,154],[249,252,157],[250,253,161],[252,255,164]]])

def ir_capture(image_queue, calibrate, stop, commands, raw_image_queue):
    dev = HTPA(0x1A)
    max_val = 0
    min_val = 0

    while not stop.isSet():

        while not commands.empty():
            cmd = commands.get()
            print "applying command"
            print cmd

            if cmd[0] == 'bias':
                dev.set_bias_current(cmd[1])
            elif cmd[0] == 'clock':
                dev.set_clock_speed(cmd[1])
            elif cmd[0] == 'cm':
                dev.set_cm_current(cmd[1])

        if calibrate.isSet():
            print "IR sensor calibrating"
            dev.measure_observed_offset()
            max_val = 0
            min_val = 0
            calibrate.clear()

        print("Capturing image")
        (pixel_values, ptats) = dev.capture_image()
        im = dev.temperature_compensation(pixel_values, ptats)
        im = dev.offset_compensation(im)
        im = dev.sensitivity_compensation(im)

        if (max_val == min_val):
            max_val = np.max(im)
            min_val = np.min(im)
        else:
            max_val = max_val * 0.75 + np.max(im) * 0.25
            min_val = min_val * 0.75 + np.min(im) * 0.25

        raw_image_queue.put(copy.copy(im))

        im = (im - min_val) / (max_val - min_val)

    	im[im > 1] = 1
    	im[im < 0] = 0
    	im = np.fliplr(im)

        new_image = np.uint8(255 * im)
        image_queue.put(new_image)

    print "Closing, cleaning up"
    dev.close()

# user interface component
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

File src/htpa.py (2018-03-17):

from periphery import I2C
import time
import numpy as np
import copy
import struct

class HTPA:
	def __init__(self, address, revision="2018"):
		self.address = address
		self.i2c = I2C("/dev/i2c-1")

		if revision == "2018":
			self.blockshift = 4
		else:
			self.blockshift = 2

		wakeup_and_blind = self.generate_command(0x01, 0x01) # wake up the device
		adc_res = self.generate_command(0x03, 0x0C) # set ADC resolution to 16 bits
		pull_ups = self.generate_command(0x09, 0x88)

		print("Initializing capture settings")

		self.send_command(wakeup_and_blind)
		self.send_command(adc_res)
		self.send_command(pull_ups)

		self.set_bias_current(0x05)
		self.set_clock_speed(0x15)
		self.set_cm_current(0x0C)

		print ("Grabbing EEPROM data")

		eeprom = self.get_eeprom()
		self.extract_eeprom_parameters(eeprom)
		self.eeprom = eeprom

		# initialize offset to zero
		self.offset = np.zeros((32, 32))

	def set_bias_current(self, bias):
		if bias > 31:
			bias = 31
		if bias < 0:
			bias = 0

		bias = int(bias)

		bias_top = self.generate_command(0x04, bias)
		bias_bottom = self.generate_command(0x05, bias)

		self.send_command(bias_top)
		self.send_command(bias_bottom)

	def set_clock_speed(self, clk):
		if clk > 63:
			clk = 63
		if clk < 0:
			clk = 0

		clk = int(clk)

		clk_speed = self.generate_command(0x06, clk)

		self.send_command(clk_speed)

	def set_cm_current(self, cm):
		if cm > 31:
			cm = 31
		if cm < 0:
			cm = 0

		cm = int(cm)

		cm_top = self.generate_command(0x07, cm)
		cm_bottom = self.generate_command(0x08, cm)

		self.send_command(cm_top)
		self.send_command(cm_bottom)

	def get_eeprom(self, eeprom_address=0x50):
		# Two separate I2C transfers in case the buffer size is small
		q1 = [I2C.Message([0x00, 0x00]), I2C.Message([0x00]*4000, read=True)]
		q2 = [I2C.Message([0x0f, 0xa0]), I2C.Message([0x00]*4000, read=True)]
		self.i2c.transfer(eeprom_address, q1)
		self.i2c.transfer(eeprom_address, q2)
		return np.array(q1[1].data + q2[1].data)

	def extract_eeprom_parameters(self, eeprom):
		self.VddComp = eeprom[0x0540:0x0740:2] + (eeprom[0x0541:0x0740:2] << 8)

		ThGrad =   eeprom[0x0740:0x0F40:2] + (eeprom[0x0741:0x0F40:2] << 8)
		ThGrad = [tg - 65536 if tg >= 32768 else tg for tg in ThGrad]
		ThGrad = np.reshape(ThGrad, (32, 32))
		ThGrad[16:,:] = np.flipud(ThGrad[16:,:])
		self.ThGrad = ThGrad

		ThOffset = eeprom[0x0F40:0x1740:2] + (eeprom[0x0F41:0x1740:2] << 8)
		ThOffset = np.reshape(ThOffset, (32, 32))
		ThOffset[16:,:] = np.flipud(ThOffset[16:,:])
		self.ThOffset = ThOffset

		P =        eeprom[0x1740::2] + (eeprom[0x1741::2] << 8)
		P = np.reshape(P, (32, 32))
		P[16:, :] = np.flipud(P[16:,:])
		self.P = P

		epsilon = float(eeprom[0x000D])
		GlobalGain = eeprom[0x0055] + (eeprom[0x0056] << 8)
		Pmin = eeprom[0x0000:0x0004]
		Pmax = eeprom[0x0004:0x0008]
		Pmin = struct.unpack('f', reduce(lambda a,b: a+b, [chr(p) for p in Pmin]))[0]
		Pmax = struct.unpack('f', reduce(lambda a,b: a+b, [chr(p) for p in Pmax]))[0]
		self.PixC = (P * (Pmax - Pmin) / 65535. + Pmin) * (epsilon / 100) * float(GlobalGain) / 100

		self.gradScale = eeprom[0x0008]
		self.VddCalib = eeprom[0x0046] + (eeprom[0x0047] << 8)
		self.Vdd = 3280.0
		self.VddScaling = eeprom[0x004E]

		PTATgradient = eeprom[0x0034:0x0038]
		self.PTATgradient = struct.unpack('f', reduce(lambda a,b: a+b, [chr(p) for p in PTATgradient]))[0]
		PTAToffset = eeprom[0x0038:0x003c]
		self.PTAToffset = struct.unpack('f', reduce(lambda a,b: a+b, [chr(p) for p in PTAToffset]))[0]

	def temperature_compensation(self, im, ptat):
	    comp = np.zeros((32,32))
	    
	    Ta = np.mean(ptat) * self.PTATgradient + self.PTAToffset
		#     temperature compensated voltage
	    comp = ((self.ThGrad * Ta) / pow(2, self.gradScale)) + self.ThOffset

	    Vcomp = np.reshape(im,(32, 32)) - comp
	    return Vcomp

	def offset_compensation(self, im):
		return im - self.offset

	def sensitivity_compensation(self, im):
		return im/self.PixC

	def measure_observed_offset(self):
		print("Measuring observed offsets")
		print("    Camera should be against uniform temperature surface")
		mean_offset = np.zeros((32, 32))

		for i in range(10):
			print("    frame " + str(i))
			(p, pt) = self.capture_image()
			im = self.temperature_compensation(p, pt)
			mean_offset += im/10.0

		self.offset = mean_offset

	def measure_electrical_offset(self):
		(offsets, ptats) = self.capture_image(blind=True)
		self.offset = self.temperature_compensation(offsets, ptats)

	def capture_image(self, blind=False):
		pixel_values = np.zeros(1024)
		ptats = np.zeros(8)

		for block in range(4):
			# print("Exposing block " + str(block))
			self.send_command(self.generate_expose_block_command(block, blind=blind), wait=False)

			query = [I2C.Message([0x02]), I2C.Message([0x00], read=True)]
			expected = 1 + (block << 2)

			done = False

			while not done:
				self.i2c.transfer(self.address, query)

				if not (query[1].data[0] == expected):
					# print("Not ready, received " + str(query[1].data[0]) + ", expected " + str(expected))
					time.sleep(0.005)
				else:
					done = True

			read_block = [I2C.Message([0x0A]), I2C.Message([0x00]*258, read=True)]
			self.i2c.transfer(self.address, read_block)
			top_data = np.array(copy.copy(read_block[1].data))

			read_block = [I2C.Message([0x0B]), I2C.Message([0x00]*258, read=True)]
			self.i2c.transfer(self.address, read_block)
			bottom_data = np.array(copy.copy(read_block[1].data))

			top_data = top_data[1::2] + (top_data[0::2] << 8)
			bottom_data = bottom_data[1::2] + (bottom_data[0::2] << 8)

			pixel_values[(0+block*128):(128+block*128)] = top_data[1:]
			# bottom data is in a weird shape
			pixel_values[(992-block*128):(1024-block*128)] = bottom_data[1:33]
			pixel_values[(960-block*128):(992-block*128)] = bottom_data[33:65]
			pixel_values[(928-block*128):(960-block*128)] = bottom_data[65:97]
			pixel_values[(896-block*128):(928-block*128)] = bottom_data[97:]

			ptats[block] = top_data[0]
			ptats[7-block] = bottom_data[0]

		pixel_values = np.reshape(pixel_values, (32, 32))

		return (pixel_values, ptats)

	def generate_command(self, register, value):
		return [I2C.Message([register, value])]

	def generate_expose_block_command(self, block, blind=False):
		if blind:
			return self.generate_command(0x01, 0x09 + (block << self.blockshift) + 0x02)
		else:
			return self.generate_command(0x01, 0x09 + (block << self.blockshift))

	def send_command(self, cmd, wait=True):
		self.i2c.transfer(self.address, cmd)
		if wait:
			time.sleep(0.005) # sleep for 5 ms

	def close(self):
		sleep = self.generate_command(0x01, 0x00)
		self.send_command(sleep)

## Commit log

2016-10-26 added code and example for succesfully reading off of heimann sensor
2017-01-12 added 3D model files for filter holder
    [ir_sensor_cover.scad, ir_sensor_cover.stl]
2017-01-12 real time capture enabled, module driver spun off into separate class
2017-01-24 added case openscad files
    [back.scad, back.stl, bracket.scad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]
2017-01-24 added raspberry pi GUI
    [ir_sensor_cover.scad, ir_sensor_cover_outer.scad]
2017-01-25 reorganized case files, added IR sensor bracket
    [bracket.scad, ir_sensor_cover.scad, ir_sensor_cover.stl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]
2017-01-27 major reorganization
    [ASTMG173.xls, FB3500-500.xlsx, back.scad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]
2017-01-27 remove old files
    [ASTMG173.xls, FB3500-500.xlsx, pm_filter.csv]
2017-01-30 added physical assembly images
2017-01-30 resized assembly images
2017-01-31 added bom to readme
2017-01-31 fixed bom formatting
2018-03-17 Organize source code and remove old, unnecessary workbooks.
    [ASTMG173.xls, FB3500-500.xlsx, back.scad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]
